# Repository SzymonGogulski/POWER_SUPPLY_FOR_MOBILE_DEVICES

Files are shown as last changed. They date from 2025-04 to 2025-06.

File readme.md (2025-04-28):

**English version at the bottom.**
#  
Projekt przedstawia przykład zasilacza dla urządzeń mobilnych. Autor Szymon Gogulski
### Główne założenia projektów
1. Zasilacz jest w stanie dostarczyć 1.8A prądu ciągłego do układu zasilanego,
2. Układ zasilany jest z jednego ogniwa LIT-ION 18650.

### Pozostałe zadania
1. Wykonaj testy rzeczywistego urządzenia.
2. Przygotuj dokumentację z opisem.

### Opracowane na podstawie
1. [Battery Charge and System Load Sharing Management With MCP73871 AN1260](https://ww1.microchip.com/downloads/en/Appnotes/01260B.pdf)
2. [MAX17048-MAX17049 Datasheet](https://www.analog.com/media/en/technical-documentation/data-sheets/max17048-max17049.pdf)
3. [MCP73871 Datasheet](https://ww1.microchip.com/downloads/en/DeviceDoc/MCP73871-Data-Sheet-20002090E.pdf)
4. [TPS61022 Datasheet](https://www.ti.com/lit/gpn/TPS61022)
5. [Texas Instruments Power Designer](https://webench.ti.com/power-designer/)
6. [Adafruit Icharging](https://learn.adafruit.com/minty-boost/icharging)
***

### Schemat elektronicznych


### Płytka PCB
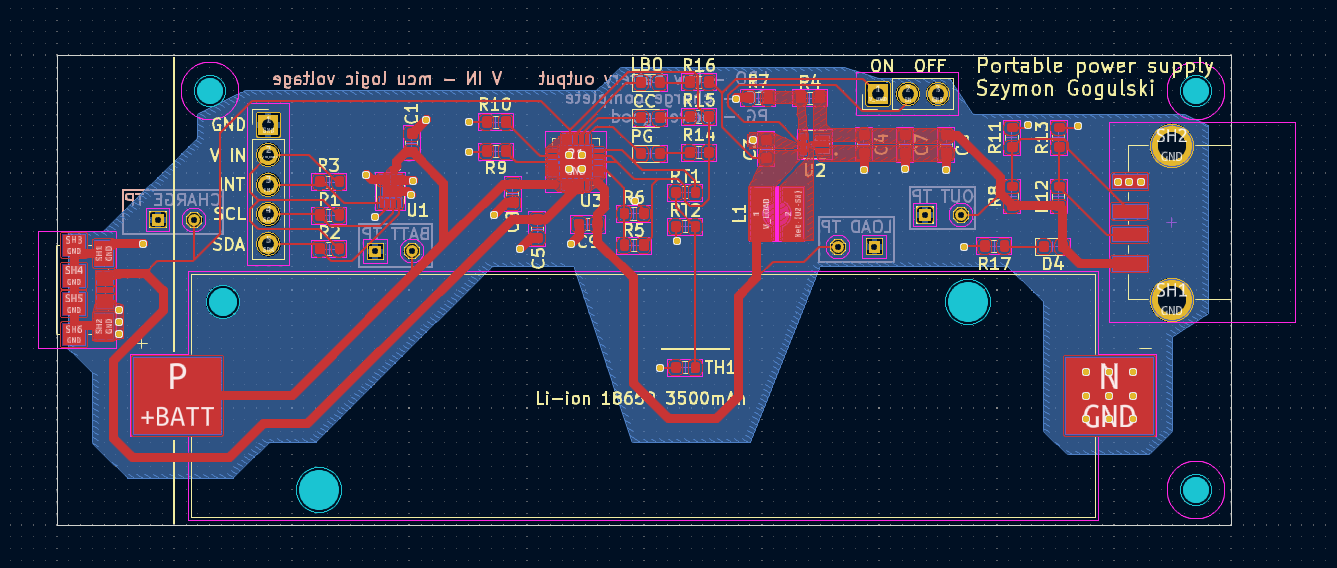
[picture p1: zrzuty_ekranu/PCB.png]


### Płytka PCB 3D
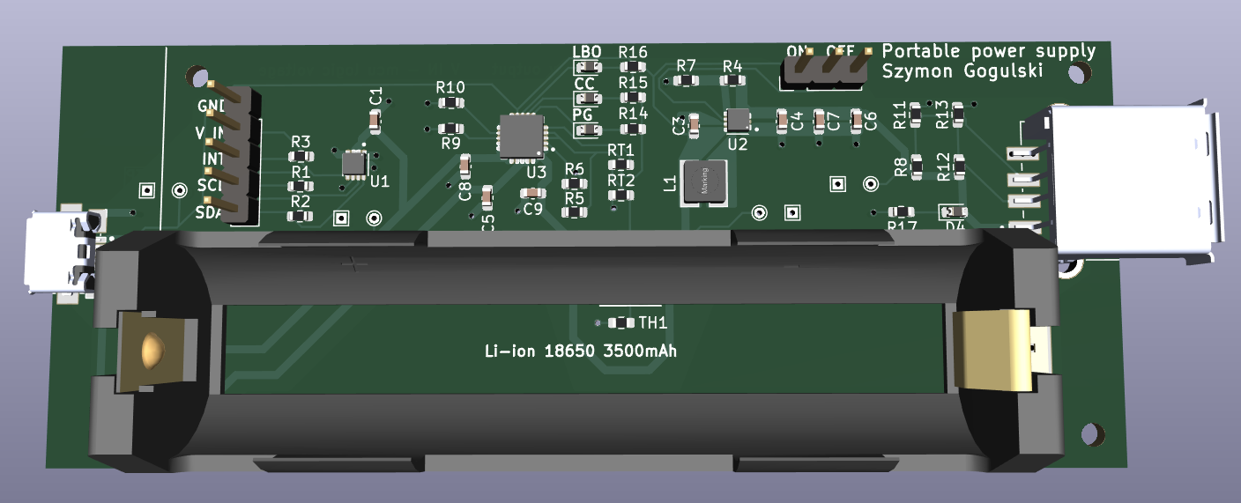
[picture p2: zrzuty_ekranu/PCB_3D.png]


### Płytka PCB 3D
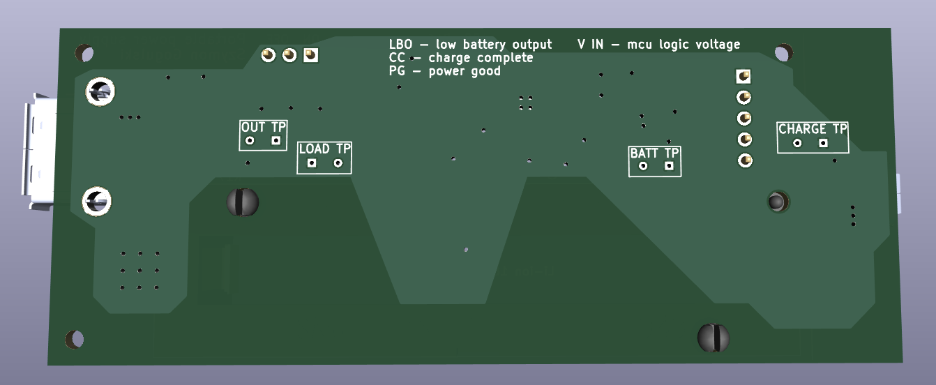
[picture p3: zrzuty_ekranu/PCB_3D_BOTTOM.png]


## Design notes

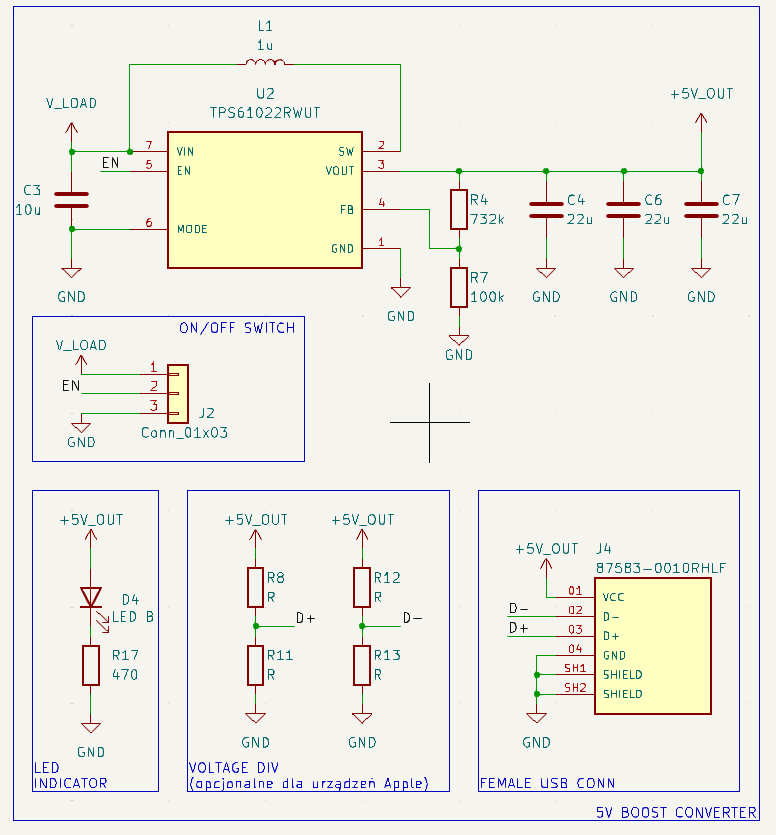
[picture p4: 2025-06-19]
sprawozdanie/TPS61022.png

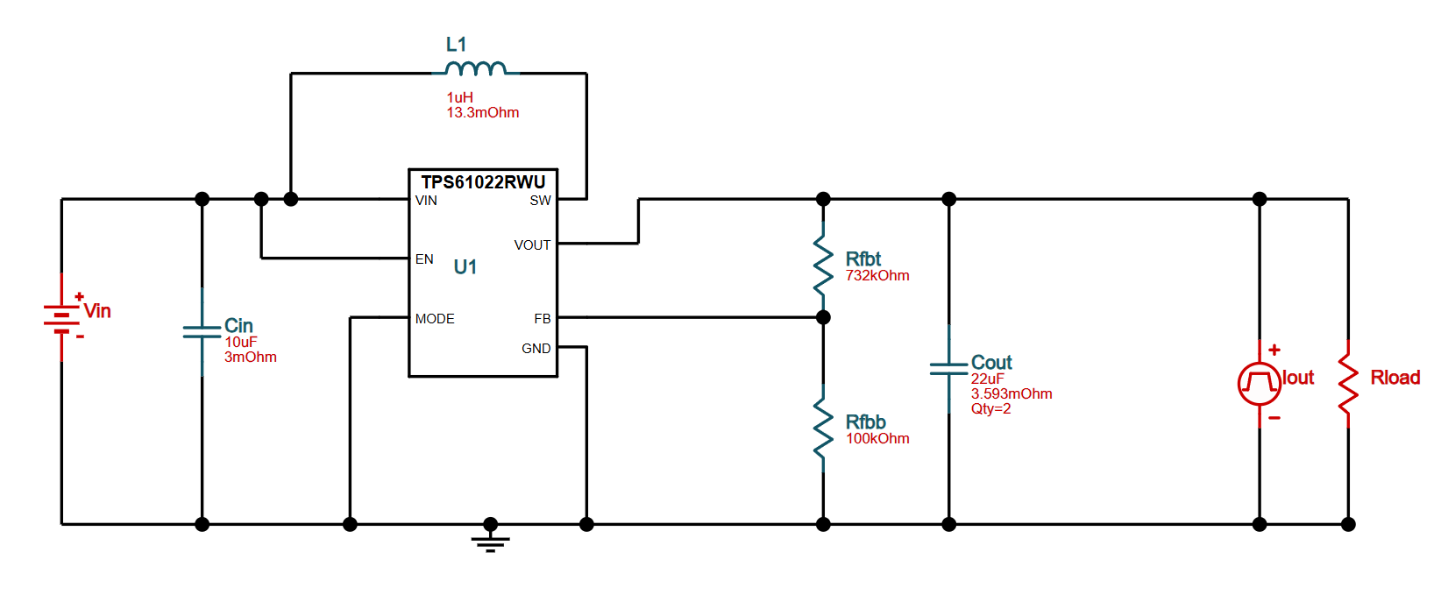
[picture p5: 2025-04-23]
dokumenty/przetwornica/09_04_25/przetwornica.png

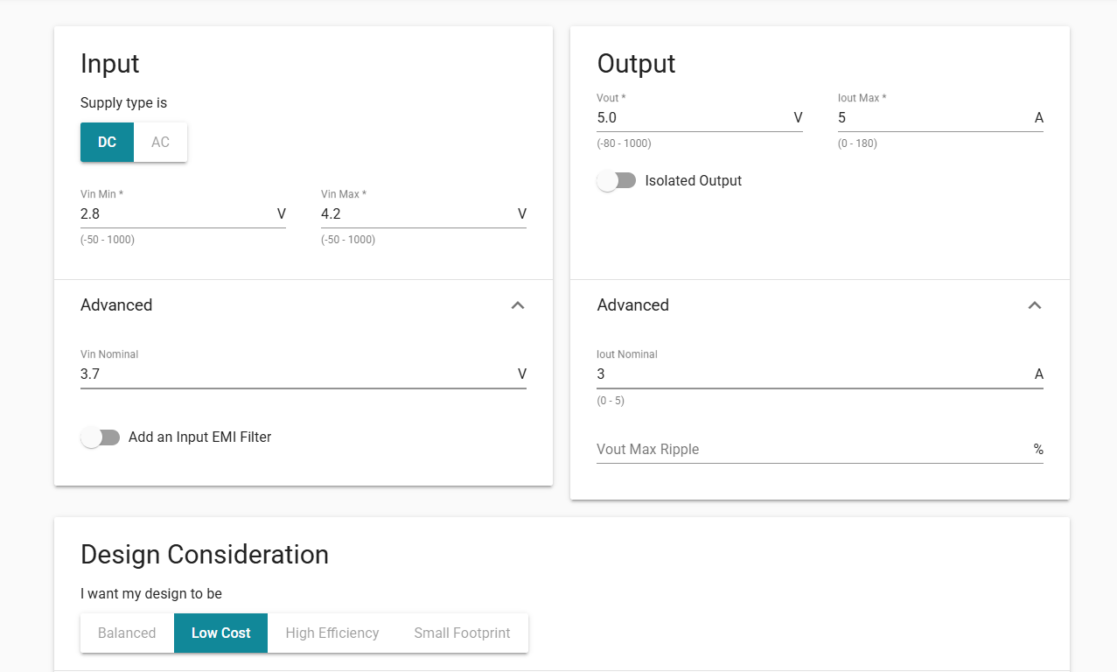
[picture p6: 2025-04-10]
dokumenty/przetwornica/parametry.png

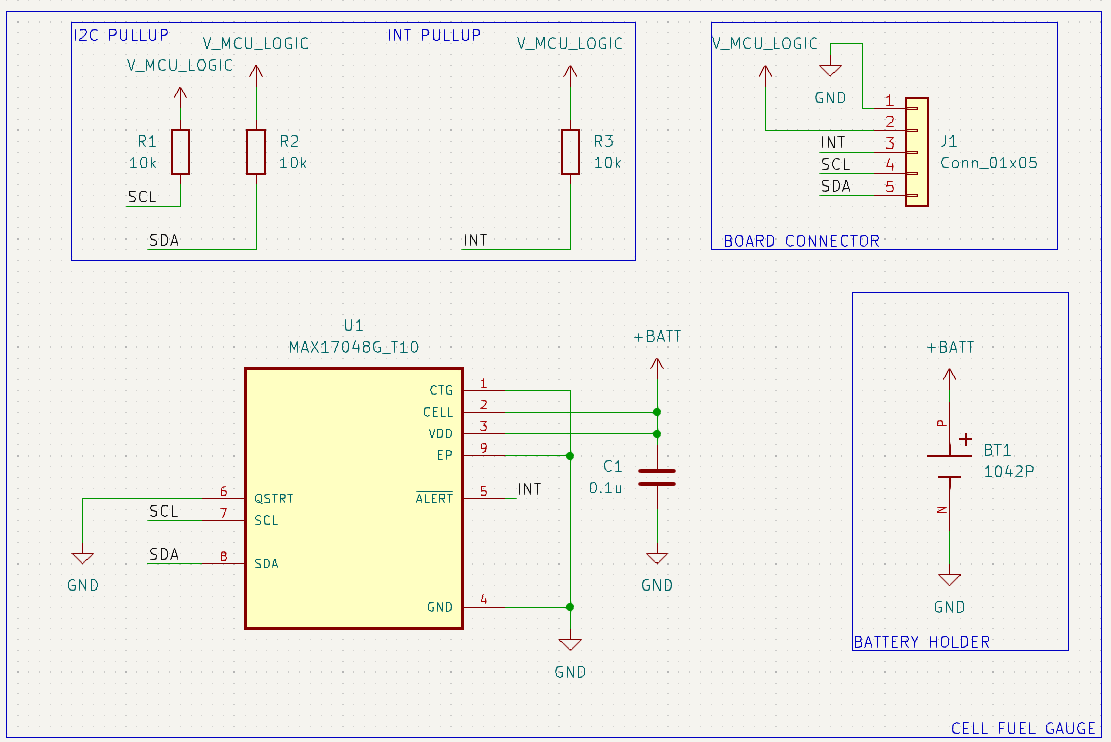
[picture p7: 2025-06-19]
sprawozdanie/MAX17048.png

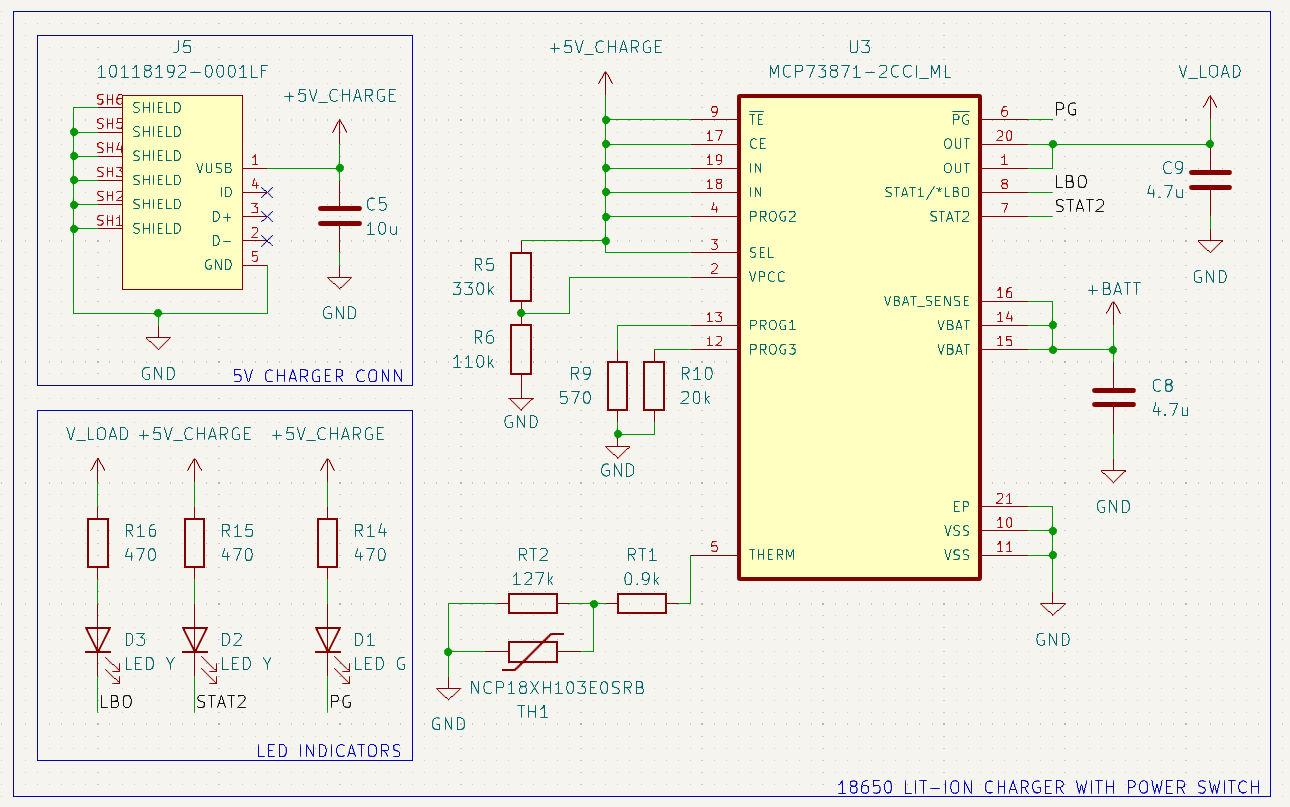
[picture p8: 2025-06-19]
sprawozdanie/MCP73871.png

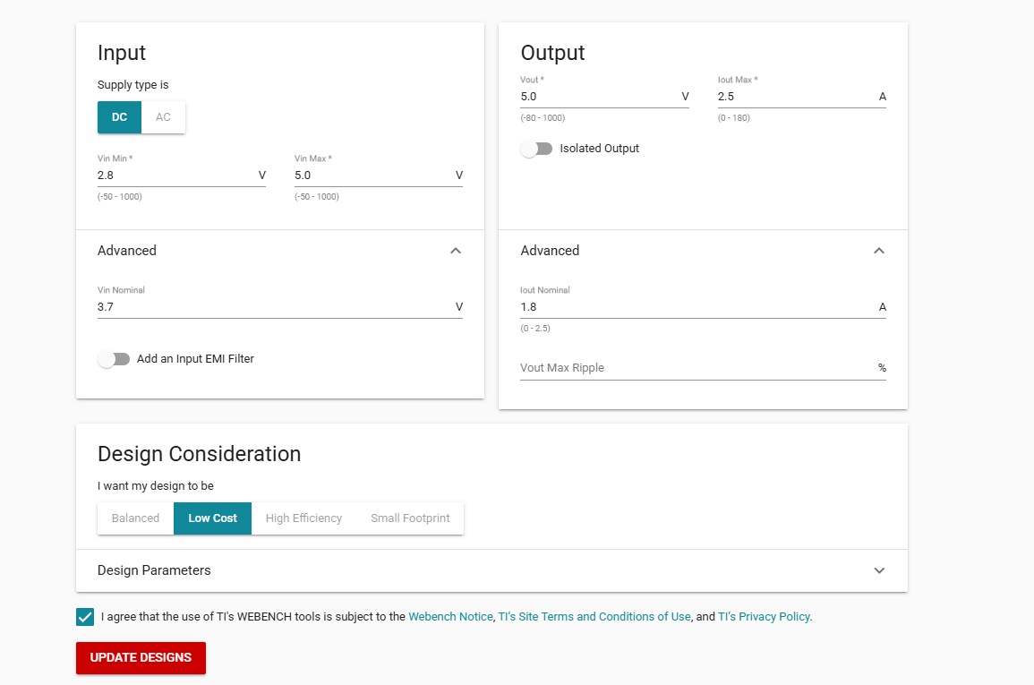
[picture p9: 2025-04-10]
dokumenty/przetwornica/09_04_25/parametry.png

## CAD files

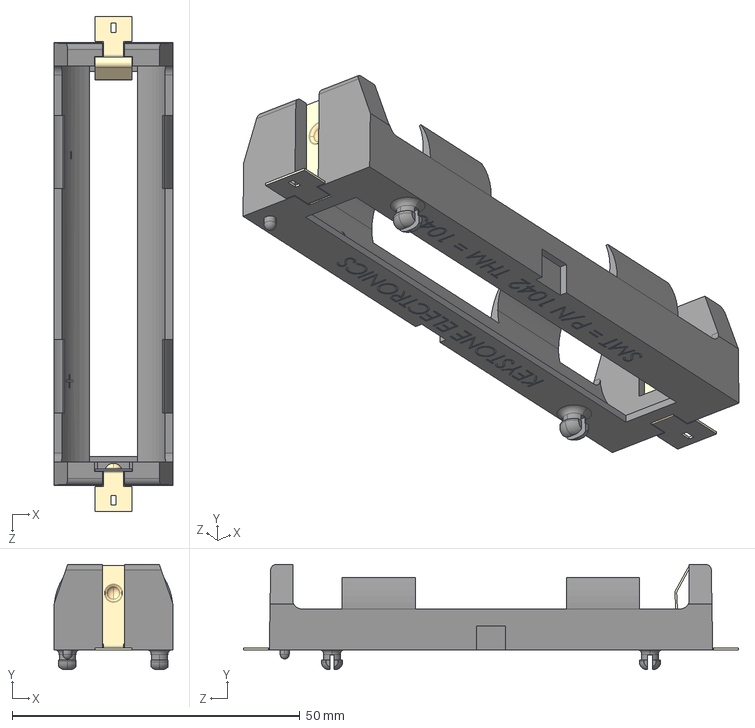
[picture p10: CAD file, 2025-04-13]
biblioteki/1042P/1042P.step
20.7 x 18.3 x 86.0 mm

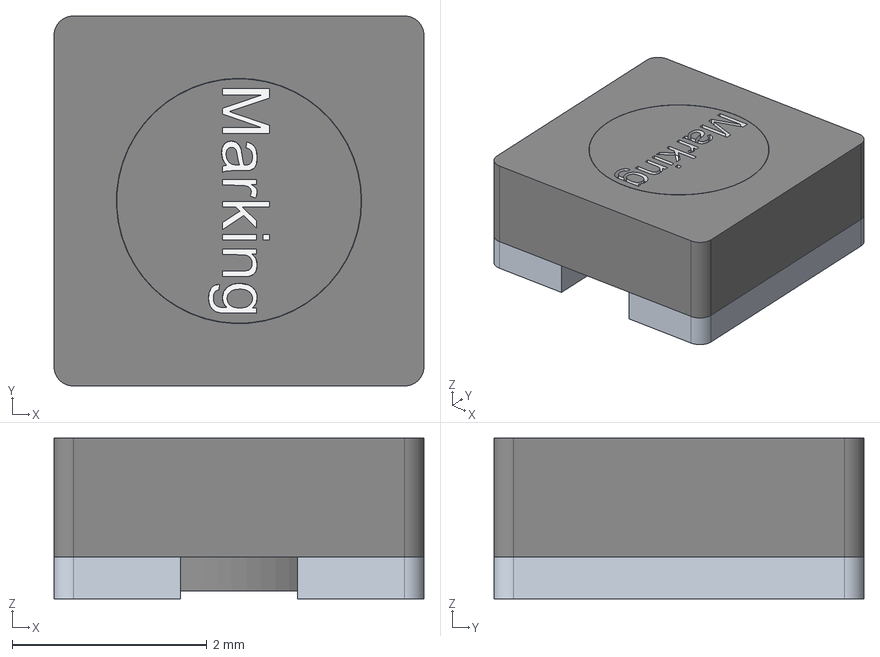
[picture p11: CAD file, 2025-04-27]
biblioteki/WE-TPC_3816/WE-TPC_3816.stp
3.80 x 3.80 x 1.65 mm

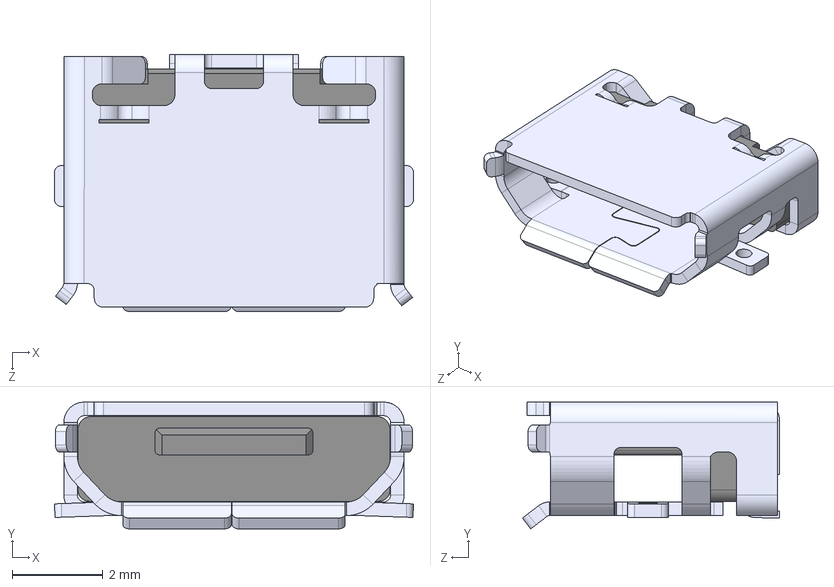
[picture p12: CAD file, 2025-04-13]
biblioteki/10118192-0001LF/10118192-0001LF.step
7.91 x 2.79 x 5.67 mm

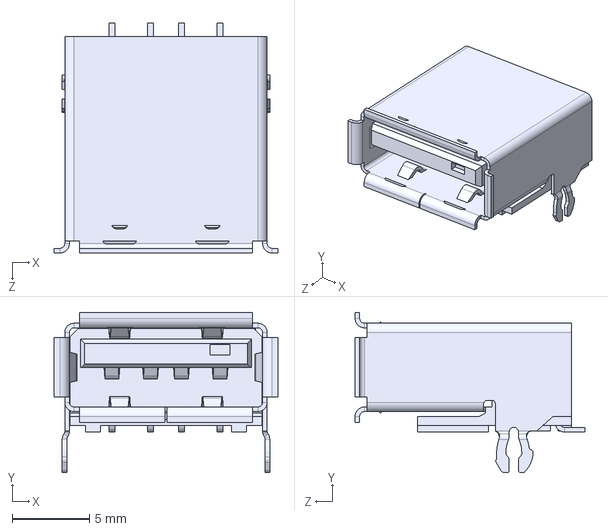
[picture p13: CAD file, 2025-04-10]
biblioteki/87583-0010RHLF/87583-0010RHLF.step
14.5 x 10.4 x 14.9 mm

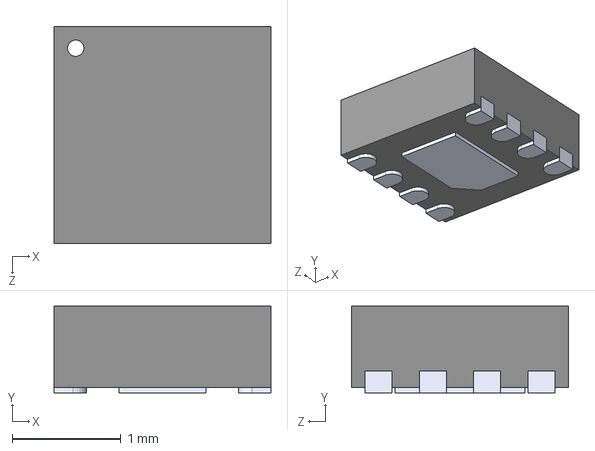
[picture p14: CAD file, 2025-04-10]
biblioteki/MAX17048G_T10/MAX17048G_T10.step
2.00 x 0.8 x 2.00 mm

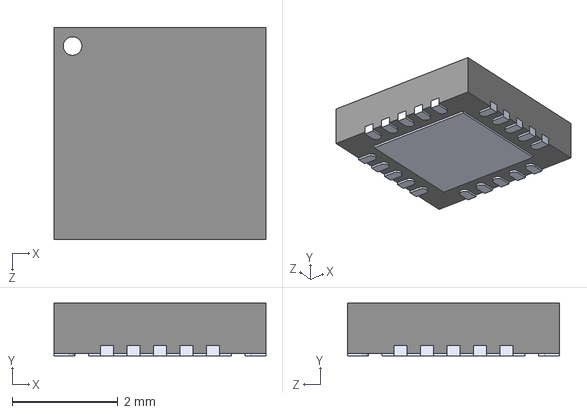
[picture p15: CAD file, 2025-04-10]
biblioteki/MCP73871-2CCI_ML/MCP73871-2CCI_ML.step
4.00 x 1.00 x 4.00 mm

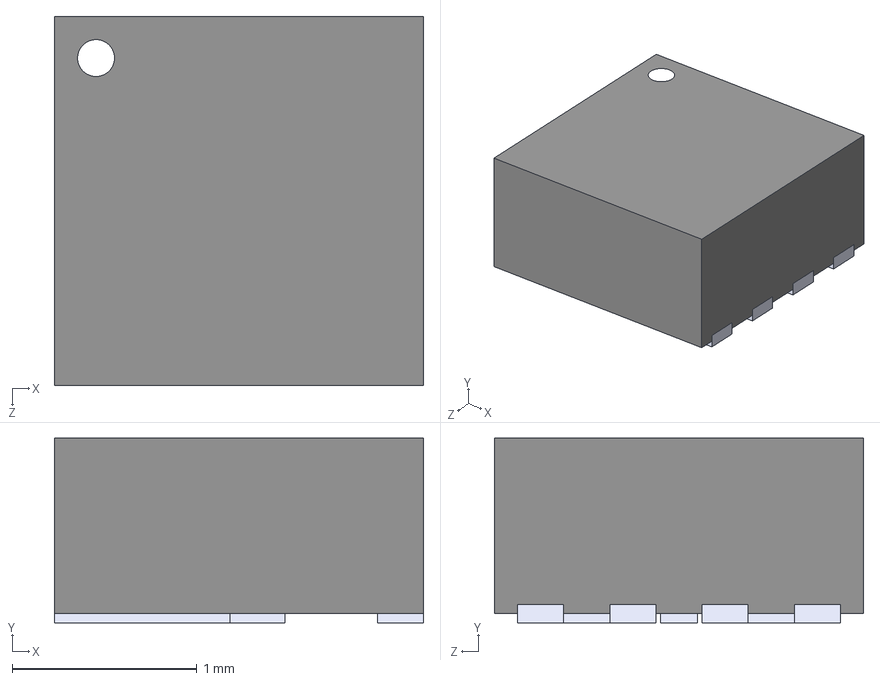
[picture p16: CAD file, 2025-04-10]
biblioteki/TPS61022RWUT/TPS61022RWUT.step
2.00 x 1.00 x 2.00 mm

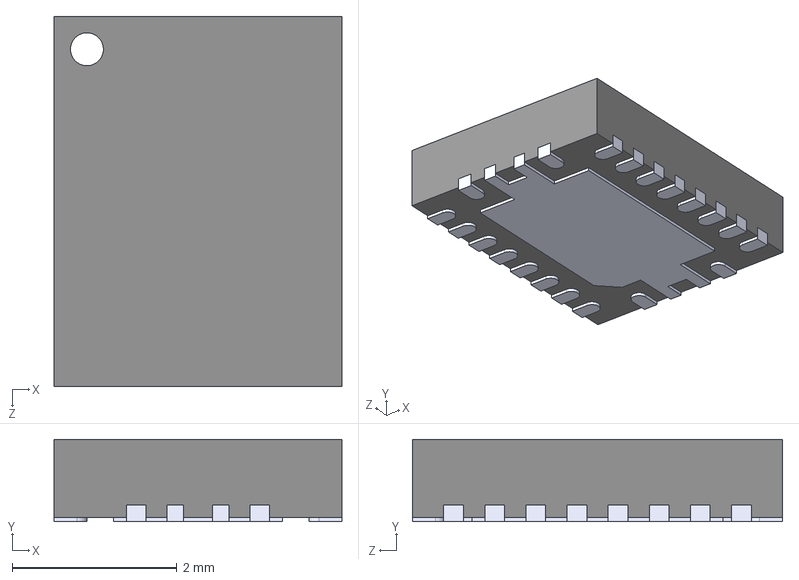
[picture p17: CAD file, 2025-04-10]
biblioteki/TPS61088RHLR/TPS61088RHLR.step
3.50 x 1.00 x 4.50 mm

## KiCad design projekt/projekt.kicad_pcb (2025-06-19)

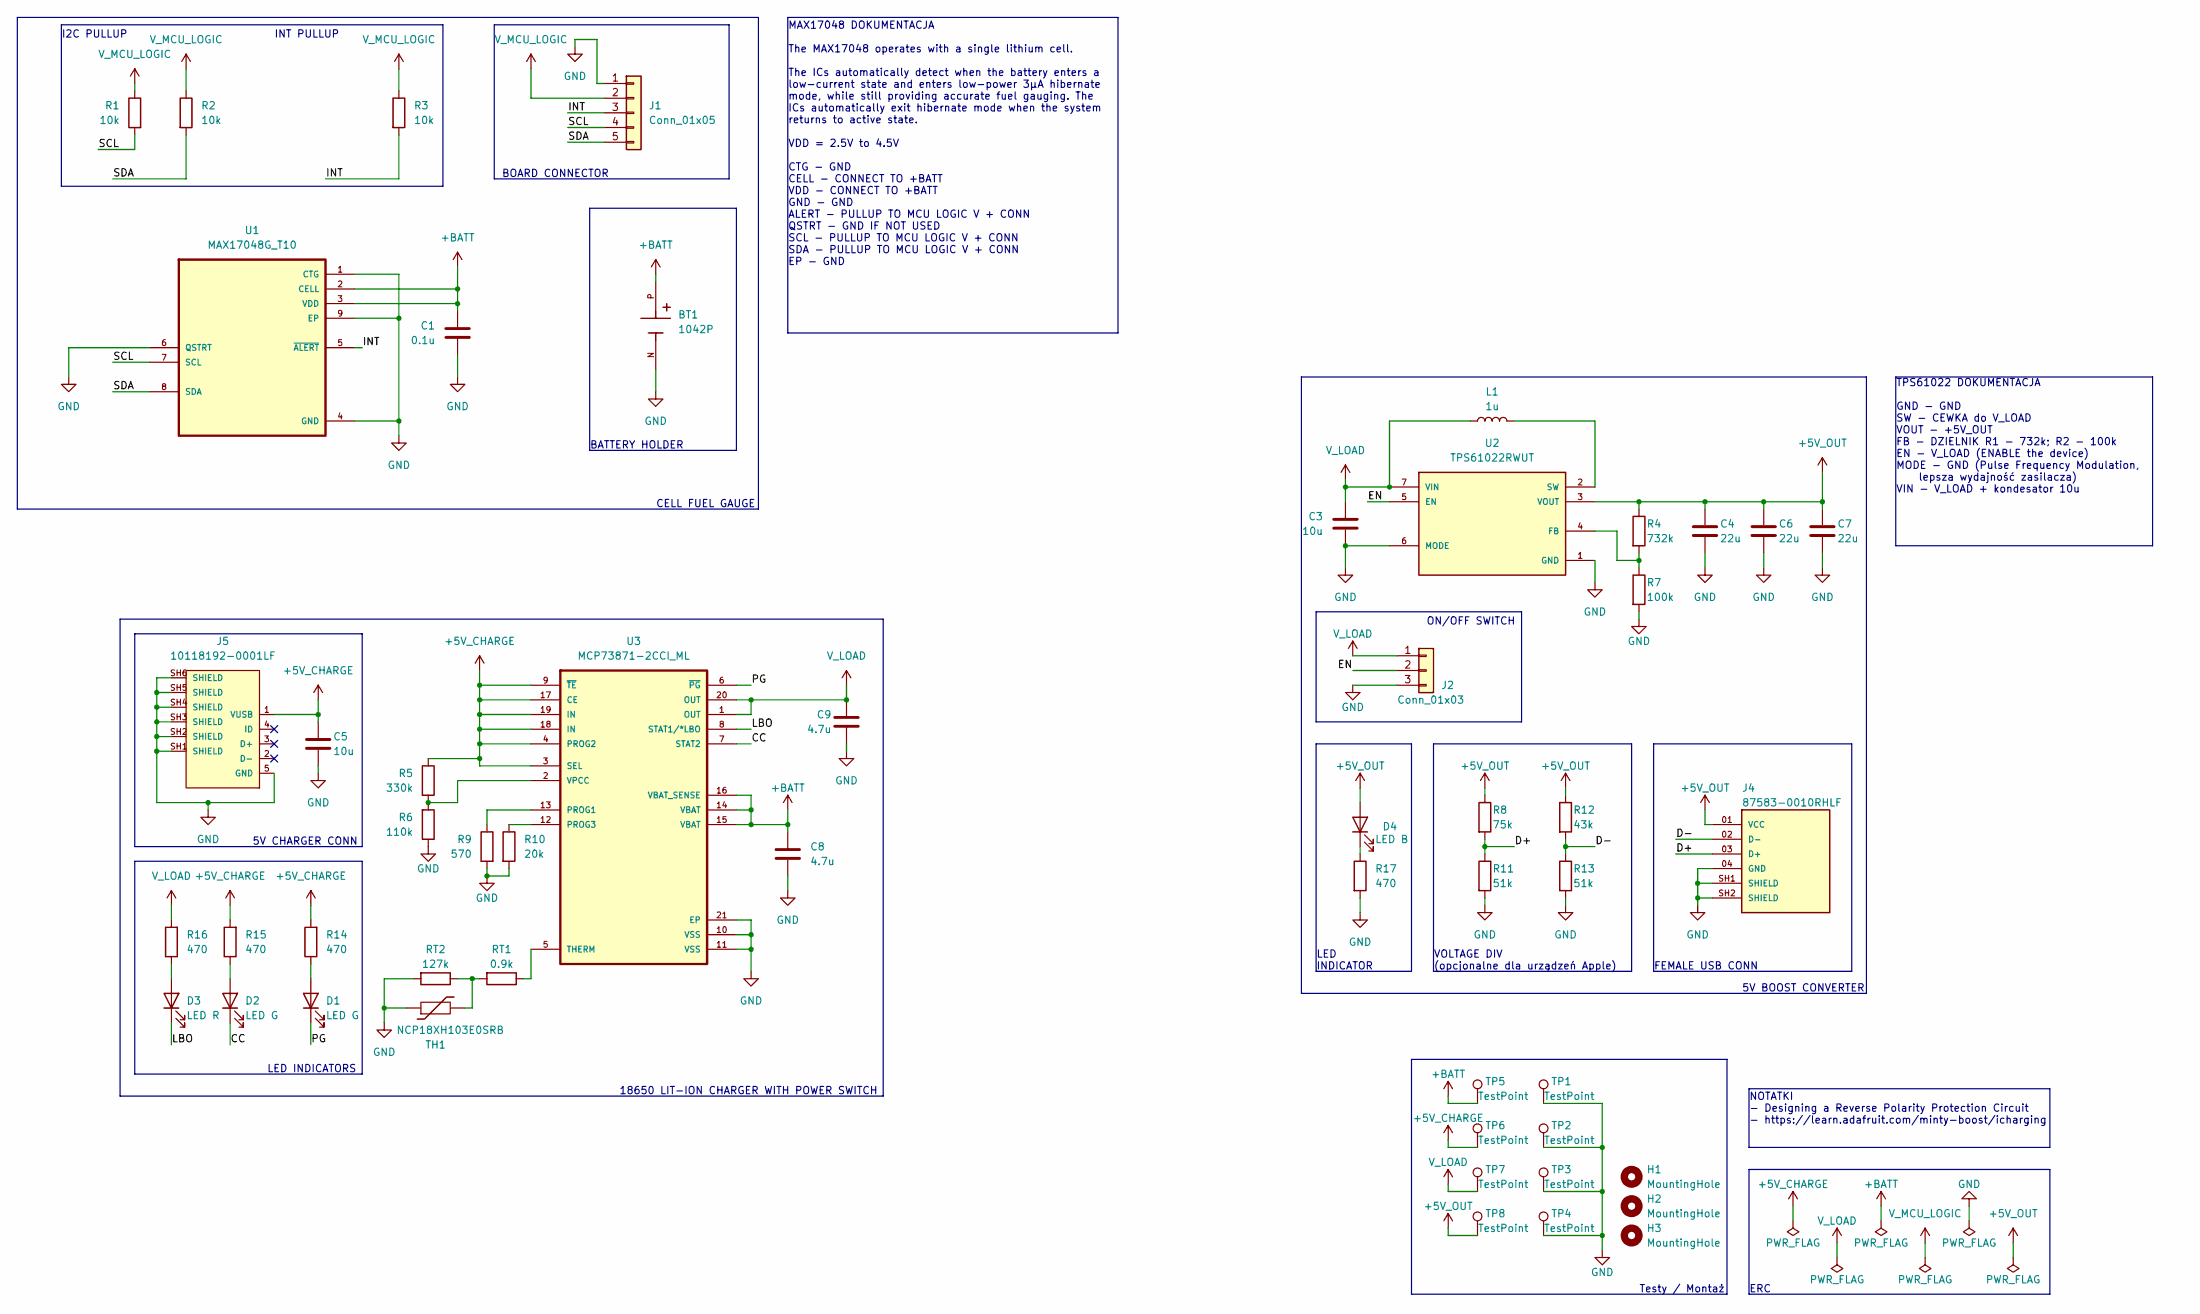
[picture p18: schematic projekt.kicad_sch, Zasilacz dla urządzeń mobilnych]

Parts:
BT1: 1042P; BAT_1042P; PARTREV E
C1: 0.1u; C_0603_1608Metric
C3, C5: 10u; C_0603_1608Metric
C4, C6, C7: 22u; C_0603_1608Metric
C8, C9: 4.7u; C_0603_1608Metric
D1, D2: LED G; D_0603_1608Metric
D3: LED R; D_0603_1608Metric
D4: LED B; D_0603_1608Metric
H1, H2, H3: MountingHole; MountingHole_2.2mm_M2
J1: Conn_01x05; PinHeader_1x05_P2.54mm_Vertical
J2: Conn_01x03; PinHeader_1x03_P2.54mm_Vertical
J4: 87583-0010RHLF; AMPHENOL_87583-0010RHLF; PARTREV AD
J5: 10118192-0001LF; AMPHENOL_10118192-0001LF; PARTREV B
L1: 1u; WE-TPC_3816
R1, R2, R3: 10k; R_0603_1608Metric
R4: 732k; R_0603_1608Metric
R5: 330k; R_0603_1608Metric
R6: 110k; R_0603_1608Metric
R7: 100k; R_0603_1608Metric
R8: 75k; R_0603_1608Metric
R9: 570; R_0603_1608Metric
R10: 20k; R_0603_1608Metric
R11, R13: 51k; R_0603_1608Metric
R12: 43k; R_0603_1608Metric
R14, R15, R16, R17: 470; R_0603_1608Metric
RT1: 0.9k; R_0603_1608Metric
RT2: 127k; R_0603_1608Metric
TH1: NCP18XH103E0SRB; R_0603_1608Metric
TP1, TP2, TP3, TP4: TestPoint; TestPoint_THTPad_1.0x1.0mm_Drill0.5mm
TP5, TP6, TP7, TP8: TestPoint; TestPoint_THTPad_D1.0mm_Drill0.5mm
U1: MAX17048G_T10; SON50P200X200X80-9N; DigiKey_Part_Number MAX17048G+T10TR-ND
U2: TPS61022RWUT; CONV_TPS61022RWUT; PARTREV January 2020
U3: MCP73871-2CCI_ML; QFN50P400X400X100-21N

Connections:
+5V_CHARGE: C5.1, J5.1 (VUSB), R5.1, R14.2, R15.2, TP6.1, U3.3 (SEL), U3.4 (PROG2), U3.9 (~TE), U3.17 (CE), U3.18 (IN), U3.19 (IN)
+5V_OUT: C4.1, C6.1, C7.1, D4.2 (A), J4.01 (VCC), R4.1, R8.1, R12.1, TP8.1, U2.3 (VOUT)
+BATT: BT1.P, C1.1, C8.1, TP5.1, U1.2 (CELL), U1.3 (VDD), U3.14 (VBAT), U3.15 (VBAT), U3.16 (VBAT_SENSE)
/CC: D2.1 (K), U3.7 (STAT2)
/D+: J4.03 (D+), R8.2, R11.1
/D-: J4.02 (D-), R12.2, R13.1
/EN: J2.2, U2.5 (EN)
/INT: J1.3, R3.2, U1.5 (~ALERT)
/LBO: D3.1 (K), U3.8 (STAT1/*LBO)
/PG: D1.1 (K), U3.6 (~PG)
/SCL: J1.4, R1.2, U1.7 (SCL)
/SDA: J1.5, R2.2, U1.8 (SDA)
GND: BT1.N, C1.2, C3.2, C4.2, C5.2, C6.2, C7.2, C8.2, C9.2, J1.1, J2.3, J4.04 (GND), J4.SH1 (SHIELD), J4.SH2 (SHIELD), J5.5 (GND), J5.SH1 (SHIELD), J5.SH2 (SHIELD), J5.SH3 (SHIELD), J5.SH4 (SHIELD), J5.SH5 (SHIELD), J5.SH6 (SHIELD), R6.1, R7.2, R9.2, R10.2, R11.2, R13.2, R17.2, RT2.2, TH1.1, TP1.1, TP2.1, TP3.1, TP4.1, U1.1 (CTG), U1.4 (GND), U1.6 (QSTRT), U1.9 (EP), U2.1 (GND), U2.6 (MODE), U3.10 (VSS), U3.11 (VSS), U3.21 (EP)
unnamed: D1.2 (A), R14.1
unnamed: D2.2 (A), R15.1
unnamed: D3.2 (A), R16.1
unnamed: D4.1 (K), R17.1
unnamed: RT1.2, RT2.1, TH1.2
unnamed: R4.2, R7.1, U2.4 (FB)
unnamed: L1.2, U2.2 (SW)
unnamed: R9.1, U3.13 (PROG1)
unnamed: R10.1, U3.12 (PROG3)
unnamed: RT1.1, U3.5 (THERM)
unnamed: R5.2, R6.2, U3.2 (VPCC)
V_LOAD: C3.1, C9.1, J2.1, L1.1, R16.2, TP7.1, U2.7 (VIN), U3.1 (OUT), U3.20 (OUT)
V_MCU_LOGIC: J1.2, R1.1, R2.1, R3.1

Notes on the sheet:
BOARD CONNECTOR
I2C PULLUP
ERC
BATTERY HOLDER
5V BOOST CONVERTER
TPS61022 DOKUMENTACJA GND - GND SW - CEWKA do V_LOAD VOUT - +5V_OUT FB - DZIELNIK R1 - 732k; R2 - 100k EN - V_LOAD (ENABLE the device) MODE - GND (Pulse Frequency Modulation, lepsza wydajność zasilacza) VIN - V_LOAD + kondesator 10u
5V CHARGER CONN
18650 LIT-ION CHARGER WITH POWER SWITCH
LED INDICATORS
MAX17048 DOKUMENTACJA The MAX17048 operates with a single lithium cell. The ICs automatically detect when the battery enters a low-current state and enters low-power 3μA hibernate mode, while still providing accurate fuel gauging. The ICs automatically exit hibernate mode when the system returns to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
INT PULLUP
VOLTAGE DIV (opcjonalne dla urządzeń Apple)
FEMALE USB CONN
ON/OFF SWITCH
CELL FUEL GAUGE
Testy / Montaż
LED INDICATOR
NOTATKI - Designing a Reverse Polarity Protection Circuit - https://learn.adafruit.com/minty-boost/icharging

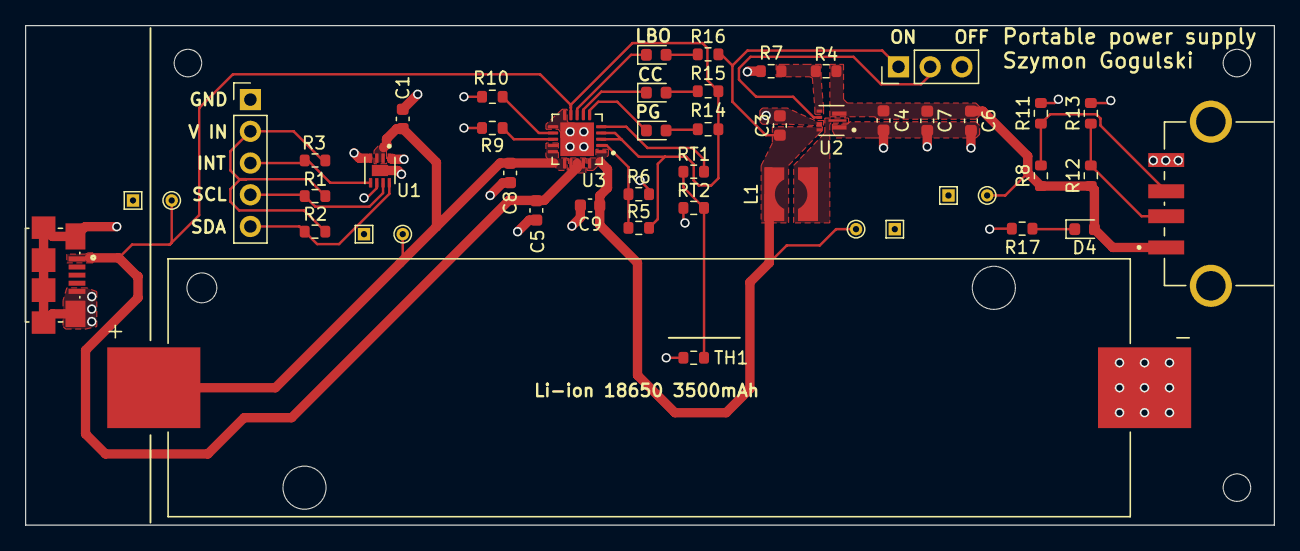
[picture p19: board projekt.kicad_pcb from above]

Board: 2 copper layers, 100.0 x 40.0 mm, 52 parts (0 on the bottom side), 26 nets.

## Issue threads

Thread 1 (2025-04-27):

Termistor

SzymonGogulski, 2025-04-27:
Sprawdź w dokumentacji czy termistor powinnien kontrolować temperaturę MCP73871 czy ogniwa 18650. Ewentualnie przenieś termistor pod ogniwo bądź bliżej MCP73871.

SzymonGogulski, 2025-04-28:
AN1260: Battery Temperature Monitor (THERM) The MCP73871 continuously monitors the battery temperature during a charge cycle by measuring the voltage between the THERM and VSS pins. Termistor mierzy temperaturę ogniwa.

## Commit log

2025-04-10 MAIN: Initial commit
    [87583-0010RHLF.step, BOM.xlsx, MAX17048G_T10.step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]
2025-04-13 MAIN: Work in progress.
    [10118192-0001LF.step, BOM.xlsx, projekt.kicad_sch]
2025-04-13 MAIN: PCB work in progress.
    [1042P.step, BOM.xlsx, projekt.kicad_pcb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]
2025-04-19 MAIN: wersja pierwsza 19.04.
    [projekt.kicad_pcb, projekt.kicad_sch]
2025-04-19 MAIN: readme.md update
    [projekt.kicad_sch]
2025-04-23 MAIN: 23.04 start wersja 2 - poprawki w schemacie.
    [projekt.kicad_pcb, projekt.kicad_sch]
2025-04-25 MAIN: Wersja 2: poprawki sieci +5V_CHARGE.
    [BOM.xlsx, projekt.kicad_pcb, projekt.kicad_sch]
2025-04-27 MAIN: Wersja 2. Sprawdzenie reguł produkcyjnych. Test wykonania u producenta.
    [projekt-B_Cu.gbr, projekt-B_Mask.gbr, projekt-B_Paste.gbr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]
2025-04-27 MAIN: wersja 2, dodałem modele 3D.
    [BOM.xlsx, WE-TPC_3816.stp, projekt.kicad_pcb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]
2025-04-28 MAIN: wersja 2: Poprawiłem termistor, readme update.
    [projekt-B_Cu.gbr, projekt-B_Mask.gbr, projekt-B_Paste.gbr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]
2025-05-02 MAIN: wersja 2: koniec, wysłane do produkcji.
    [projekt-B_Cu.gbr, projekt-B_Mask.gbr, projekt-B_Paste.gbr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]
